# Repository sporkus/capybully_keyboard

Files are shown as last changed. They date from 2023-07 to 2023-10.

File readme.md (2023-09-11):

Capybully
---

Open source capactive sensing pcb for [Bully keyboard](https://mkh.works/#bully).

### Status
PCB has been tested and is fully functional with Niz and Deskeys parts.

### Specs
- MCU: stm32F072CB

### Supported layouts
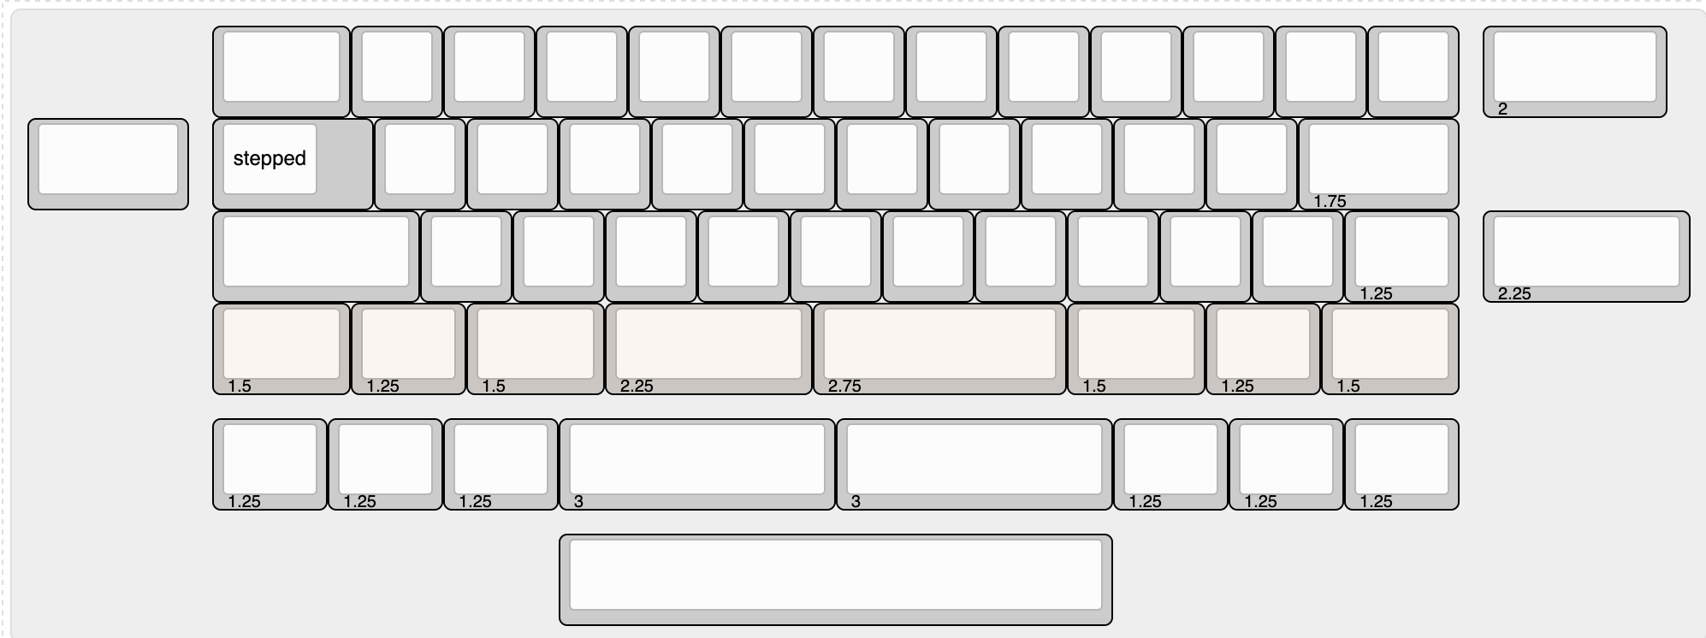
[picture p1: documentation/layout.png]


### Production files
JLCPCB [production files](pcb_production) are provided. Component positions have been verified, but as always, do your own diligence when ordering.

#### Firmware
- [See here](./firmware) for instructions, links to qmk/vial config and binaries.

#### Hardware
- 25x m2 brass standoff. 5mm long x 3mm diameter
- 50x m2 low profile screws

## Misc
#### 3D assembly preview
* [online viewer](https://3dviewer.net/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)
* [step assembly](./documentation/capybully-3D.step)

#### PCB Renders
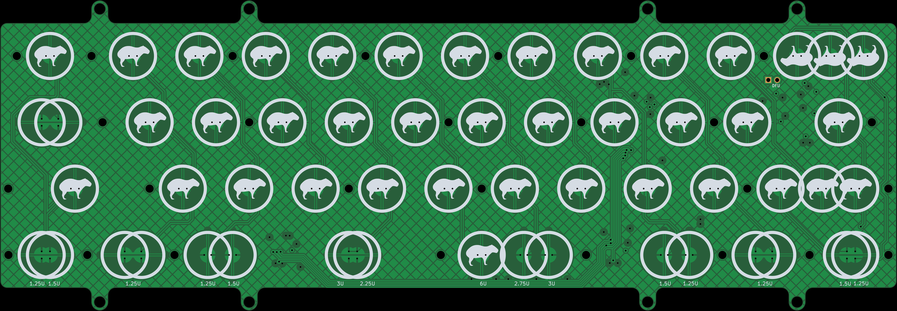
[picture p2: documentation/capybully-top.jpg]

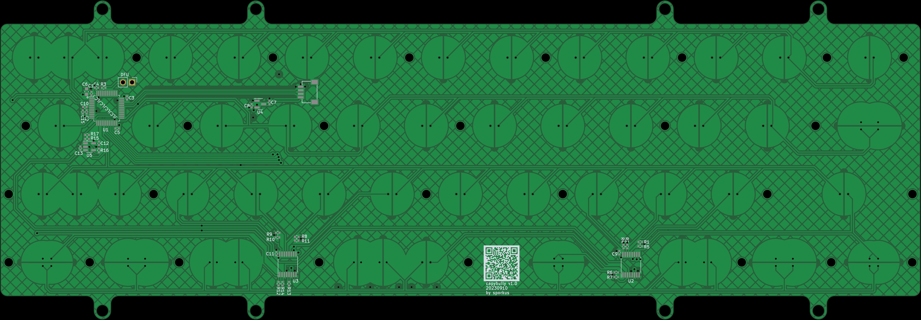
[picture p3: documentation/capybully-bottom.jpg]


#### Interactive BoM
Download and open this [html](./documentation/capybully-ibom.html) locally

#### Schematic
[pdf](./documentation/capybully-schematic.pdf)

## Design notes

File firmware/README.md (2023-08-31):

# Firmware

- [QMK and vial config](https://github.com/sporkus/qmk_userspace/tree/main/keyboards/sporkus/capybully)
- [Pre-compiled vial binary](./sporkus_capybully_vial.bin)

## First flash
Use tweezers to short the DFU pads while powering up the PCB will put it into DFU bootloader mode. Afterwards, you can use bootmagic or keycodes to enter the bootloader mode.

To flash, you can use `qmk flash` or `dfu-util` on cli. Alternatively, you can flash the binary using qmk toolbox.

## EC Matrix features
#### Tuning
The baseline for each key is different. Even if you use the same parts, they can change between assemblies. The very first time firmware is flashed, a quick auto tuning will be done (about half a minute). As long as you don't intentionally feather the keys, it should be immediately usable and not affect the tuning result.

To re-tune after assembly, you can either use the keycode `EC_CLR` to reset the configuration. 

#### Actuation point adjustment
Use the keycodes `EC_AP_I`/`EC_AP_D` to increase/decrease the actuation point.

#### Advanced users
More options can be enabled in the config.h file.
- `ECSM_TUNE_ON_BOOT`: re-tune on every boot. It's not really necessary and increases write cycles to the flash memory.
- `ECSM_DEBUG`: prints EC config and readings in console.

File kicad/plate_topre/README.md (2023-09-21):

# Topre plate

Layout option is:
* 2.25/2.75 split bars (uses 2u housing)
* Stepped/non-stepped caps lock

Other layout options are removed because it's unlikely to work well in a single plate.

See [keyboard layout editor](./capybully_plate.json) json file for reference.

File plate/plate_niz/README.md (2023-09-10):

# Niz plate

Main layout option is 2.25/2.75 split bars. 2u+ keys uses costar stabilizers.

See [keyboard layout editor](./capybully_plate.json) json file for reference.

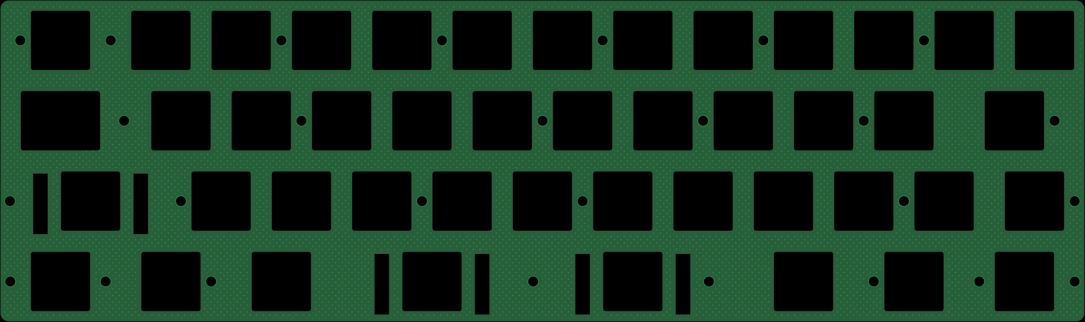
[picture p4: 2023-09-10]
plate/plate_niz/plate-top.jpg

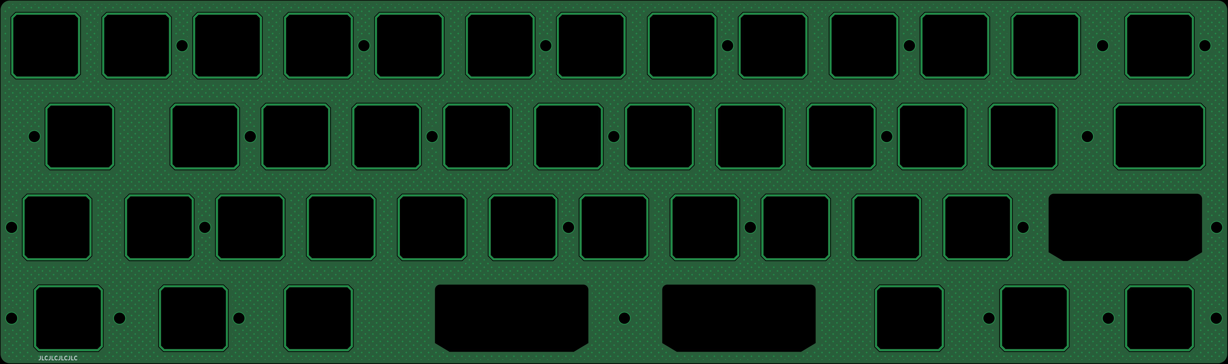
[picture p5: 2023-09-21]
plate/topre/plate-bottom.jpg

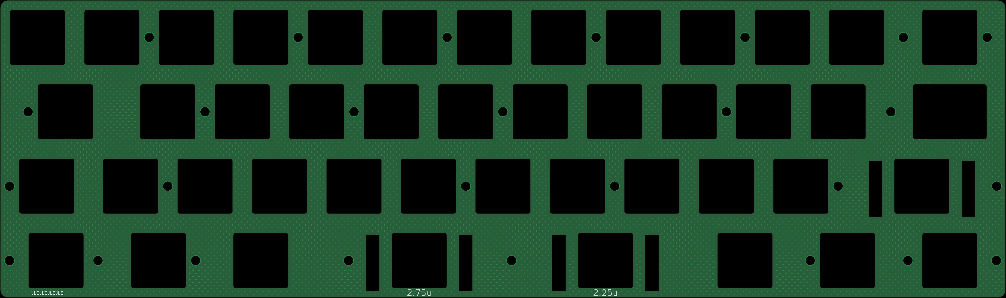
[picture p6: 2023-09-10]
plate/plate_niz/plate-bottom.jpg

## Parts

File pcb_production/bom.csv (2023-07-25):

Designator | Footprint | Quantity | Value | LCSC Part #
C1, C10, C2, C3, C4 | 0402 | 5 | 100nF | C307331
C11, C12, C5, C9 | 0402 | 4 | 100n | C307331
C13 | 0402 | 1 | 220pF NP0 | C1530
C15 | 0402 | 1 | 1u
C6 | 0603 | 1 | 10uF
C7, C8 | 0402 | 2 | 1uF | C52923
H1, H10, H11, H12, H13, H14, H15, H16, H17, H18, H19, H2, H20, H21, H22, H23, H24, H25, H26, H27, H3, H4, H5, H6, H7, H8, H9 | MountingHole_2.2mm_M2_DIN965 | 27 | MountingHole
J1 | JST-SR-4 | 1 | SM04B-SRSS-TB(LF)(SN)
R1, R10, R11, R12, R13, R14, R15, R2, R4, R5, R6, R7, R8, R9 | 0402 | 14 | 100k | C25741
R16 | 0402 | 1 | 1k | C11702
R3 | 0402 | 1 | 10k
U1 | LQFP-48_7x7mm_P0.5mm | 1 | STM32F072CBT6
U2, U3 | TSSOP-16_4.4x5mm_P0.65mm | 2 | 74HC4051 | C5645
U4 | SOT-23 | 1 | XC6206PxxxMR-Regulator_Linear | C5446
U5 | SOT-23-5 | 1 | OPA354

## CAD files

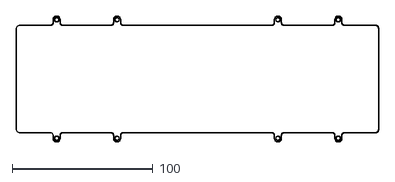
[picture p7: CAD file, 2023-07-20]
documentation/capybully-Edge_Cuts.dxf
257.2 x 89.2

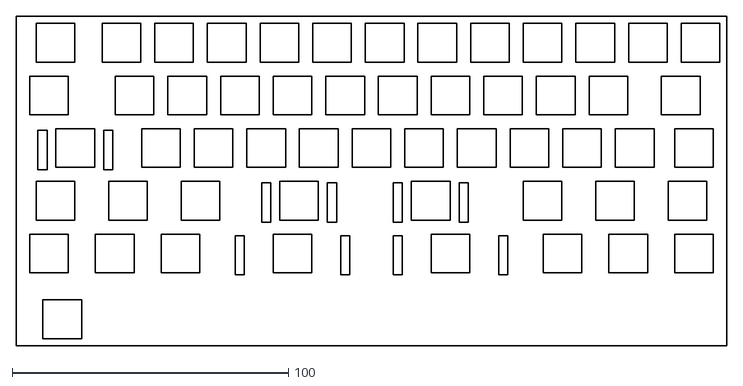
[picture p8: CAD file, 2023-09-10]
kicad/plate_niz/kle_reference.dxf
257.2 x 119.1

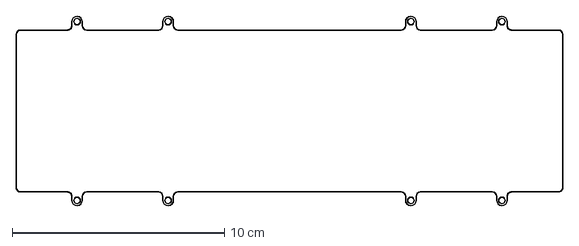
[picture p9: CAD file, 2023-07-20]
misc/edgecuts.dxf
25.7 x 8.92 cm

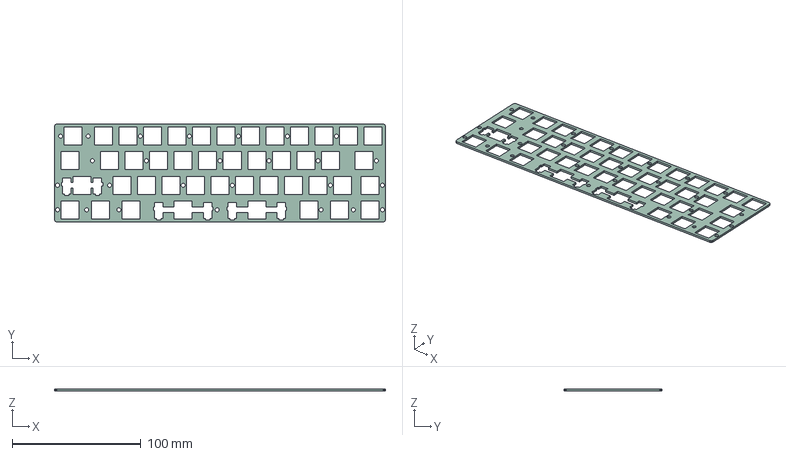
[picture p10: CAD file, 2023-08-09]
plate/plate-3D.step
257.2 x 76.2 x 1.58 mm

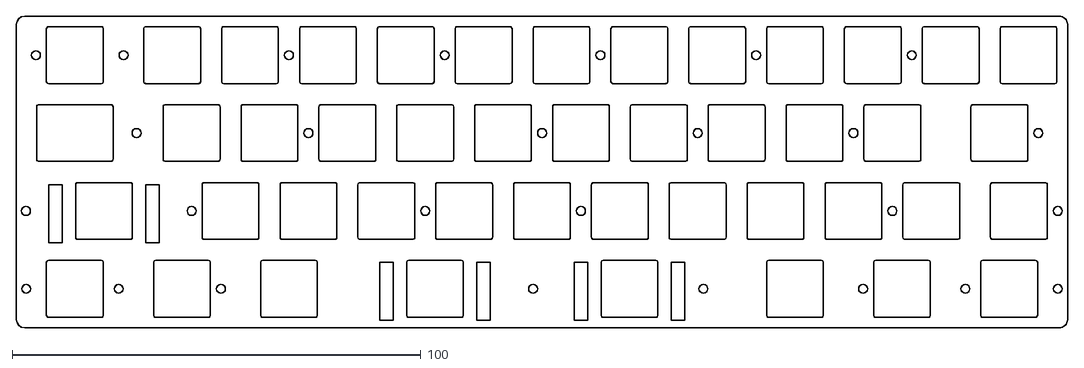
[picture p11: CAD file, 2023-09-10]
plate/plate_niz/plate-Edge_Cuts.dxf
257.2 x 76.2

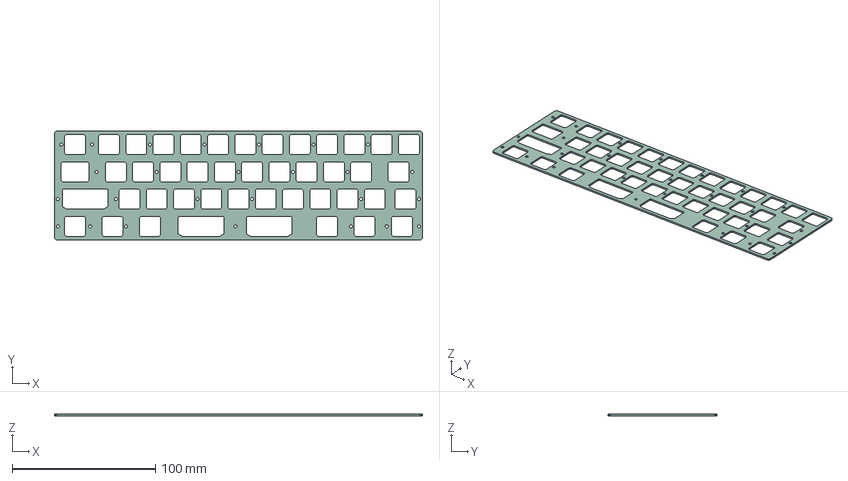
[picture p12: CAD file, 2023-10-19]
plate/topre/plate-3D.step
257.2 x 76.2 x 1.18 mm

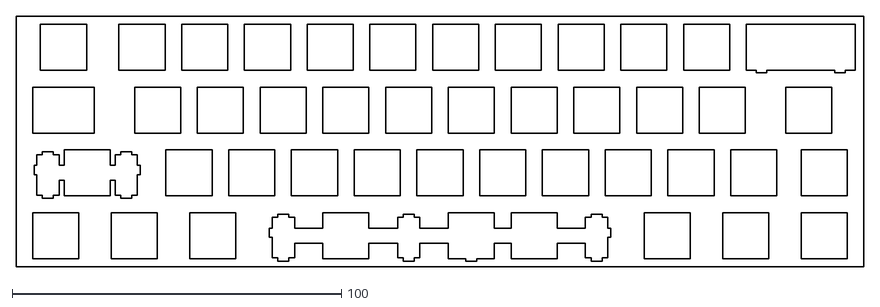
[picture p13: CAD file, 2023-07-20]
misc/3u_6u_plate.dxf
257.2 x 76.2

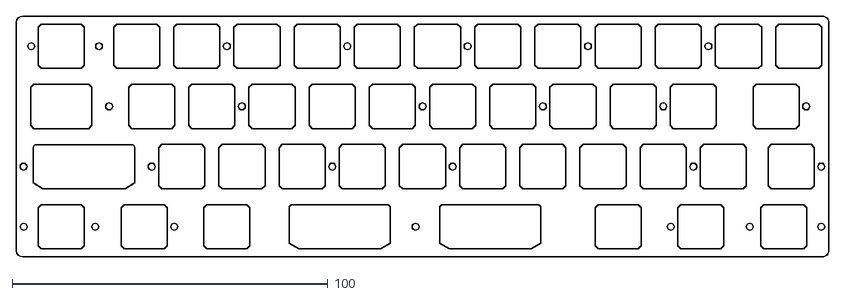
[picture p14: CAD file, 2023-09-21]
plate/topre/plate-Edge_Cuts.dxf
257.2 x 76.2

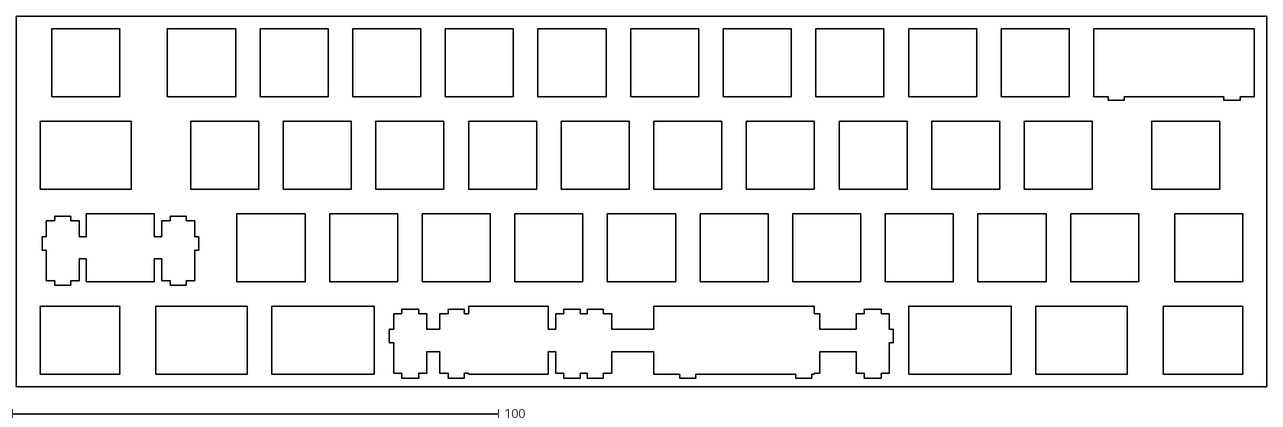
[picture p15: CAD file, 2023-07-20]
misc/b75c8ba988832cb8d0211764c9687bd89171a611_switch.dxf
257.2 x 76.2

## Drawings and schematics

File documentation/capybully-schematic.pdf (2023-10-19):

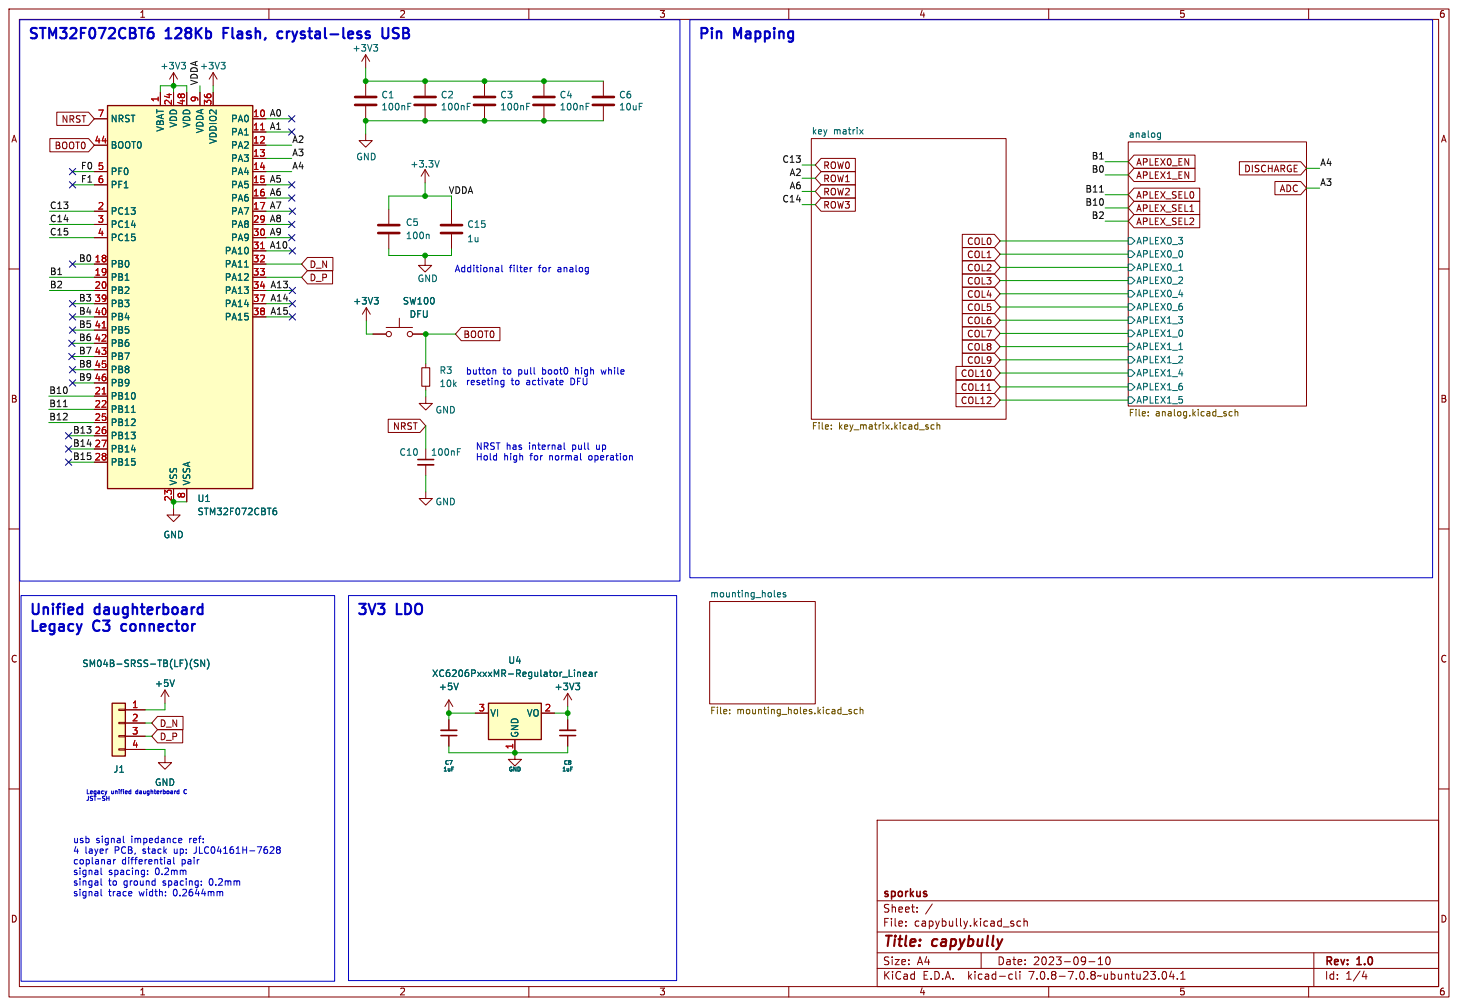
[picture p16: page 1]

1 PA0 10 PA1 11 PA2 12 PA3 13 PA4 14 PA5 15 PA6 16 PA7 17 PB0 18 PB1 19 PC13 2 PB2 20 PB10 21 PB11 22 VSS 23 VDD 24 PB12 25 PB13 26 PB14 27 PB15 28 PA8 29 PC14 3 PA9 30 PA10 31 PA11 32 PA12 33 PA13 34 VDDIO2 36 PA14 37 PA15 38 PB3 39 PC15 4 PB4 40 PB5 41 PB6 42 PB7 43 BOOT0 44 PB8 45 PB9 46 VDD 48 PF0 5 PF1 6 NRST 7 VSSA

button to pull boot0 high while

J1 SM04B-SRSS-TB(LF)(SN) 1

File: capybully.kicad_sch Sheet: / sporkus

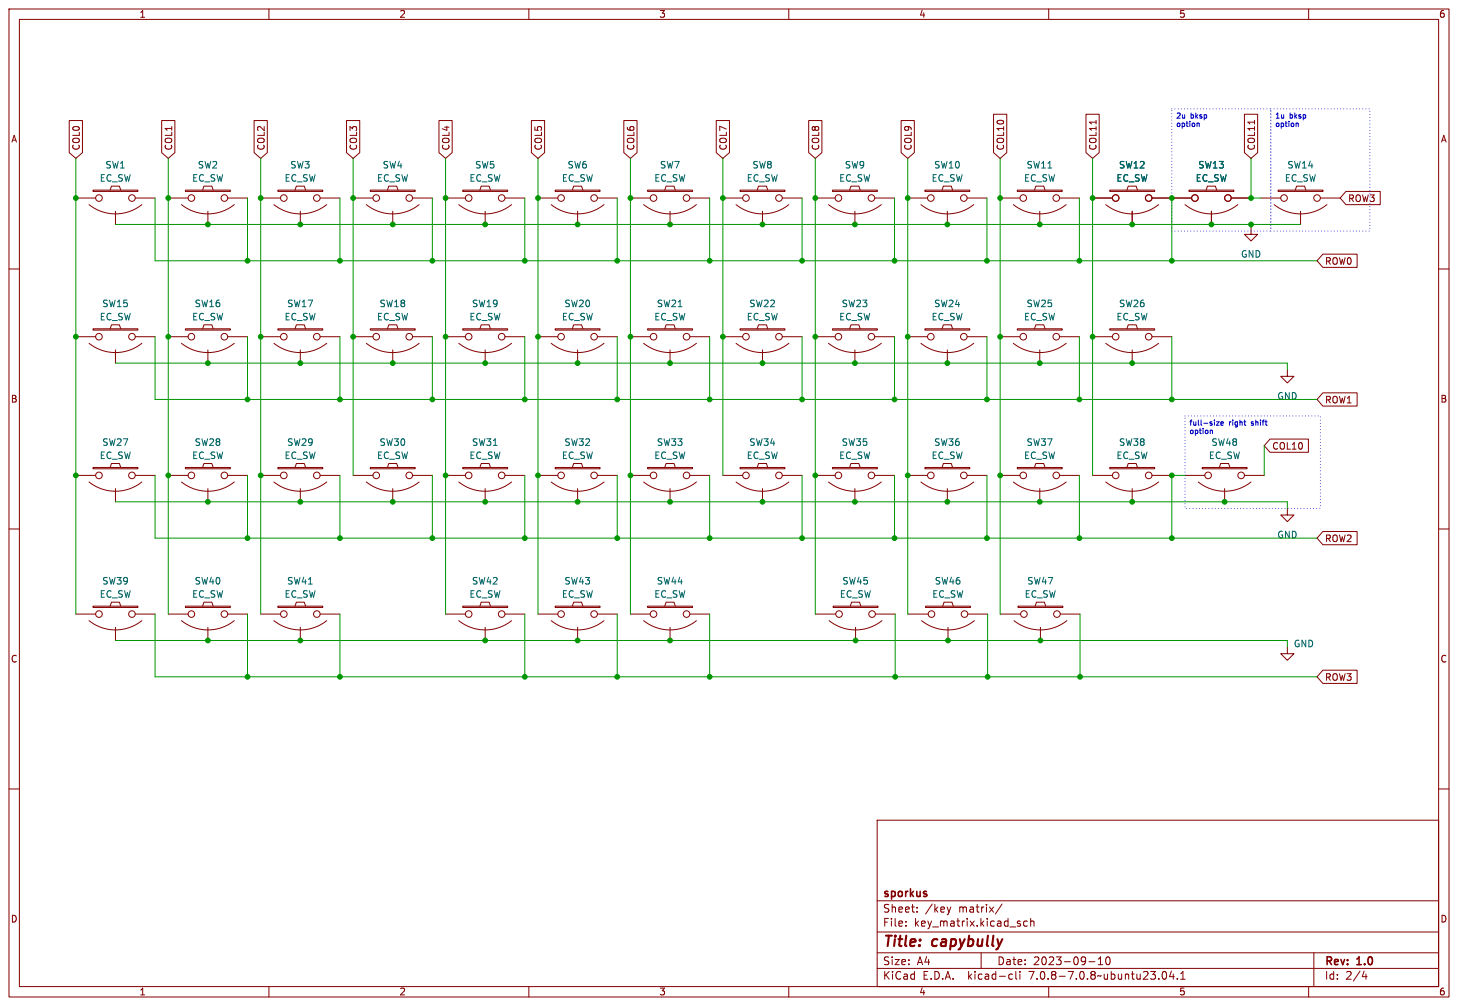
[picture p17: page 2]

File: key_matrix.kicad_sch Sheet: /key matrix/ sporkus SW43 EC_SW

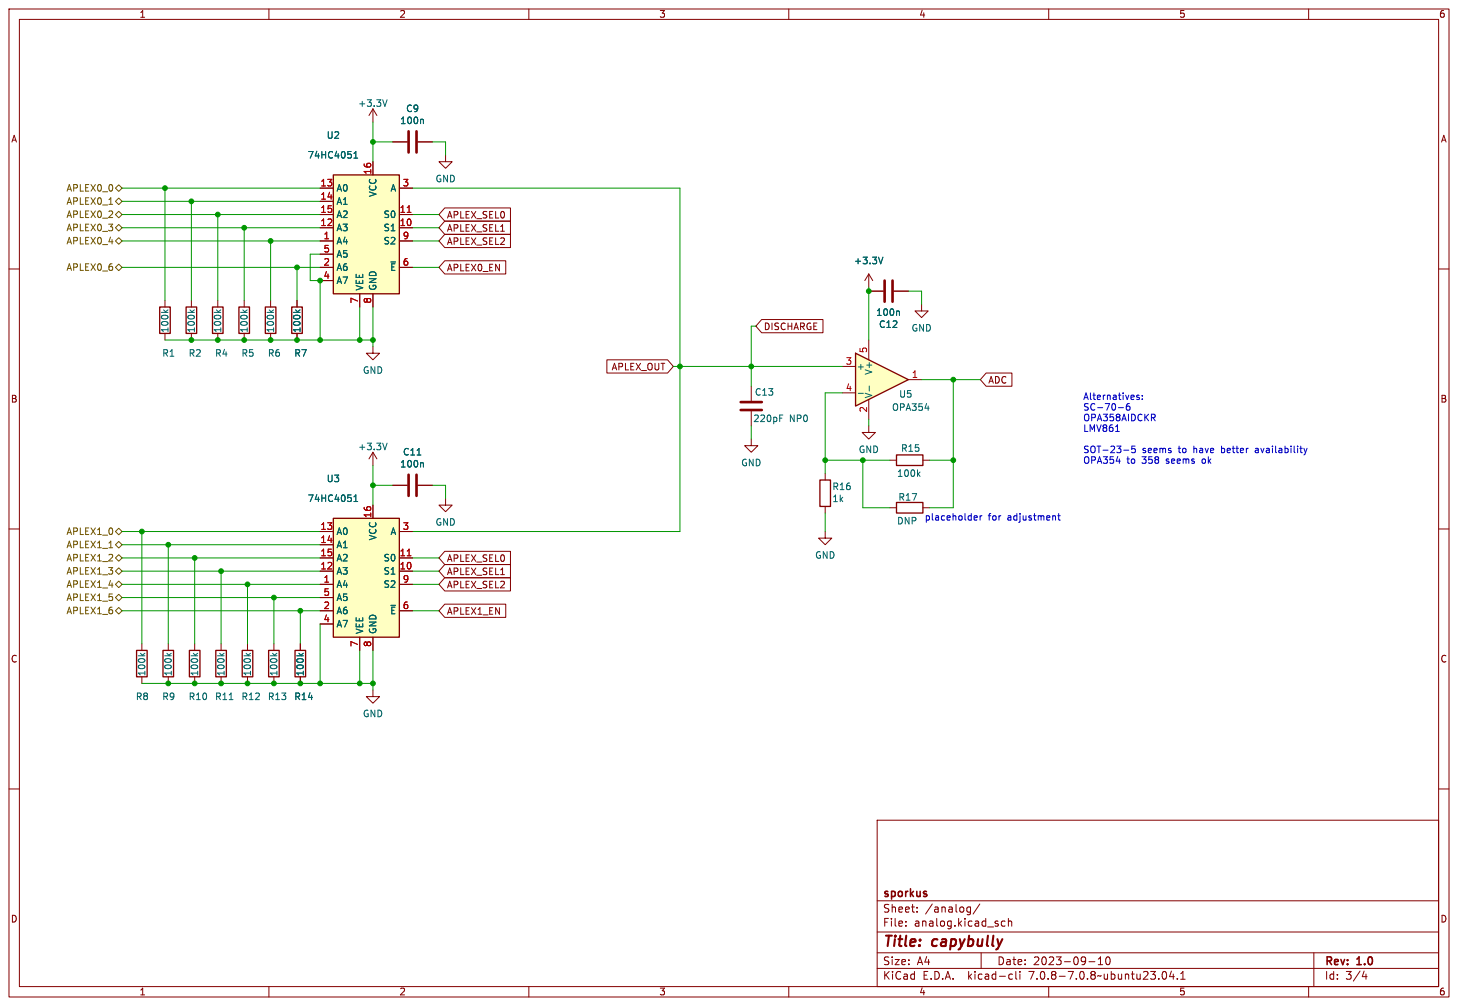
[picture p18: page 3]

sporkus
File: analog.kicad_sch Sheet: /analog/
Id: 3/4 Title: capybully

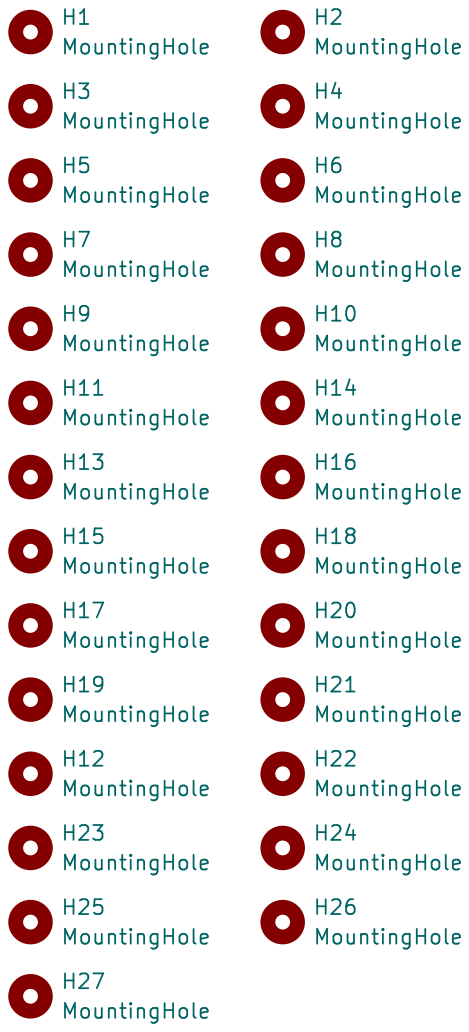
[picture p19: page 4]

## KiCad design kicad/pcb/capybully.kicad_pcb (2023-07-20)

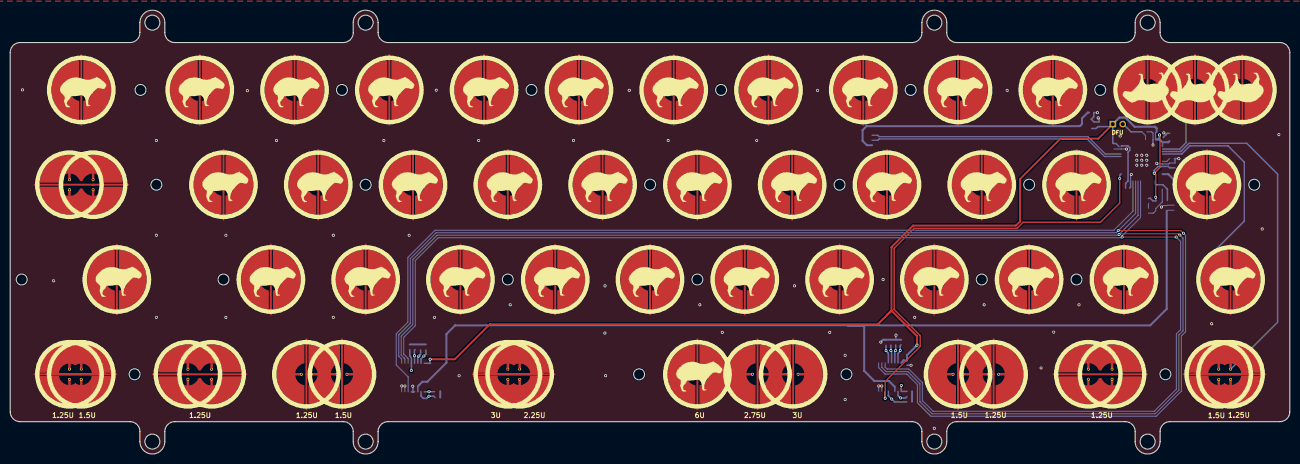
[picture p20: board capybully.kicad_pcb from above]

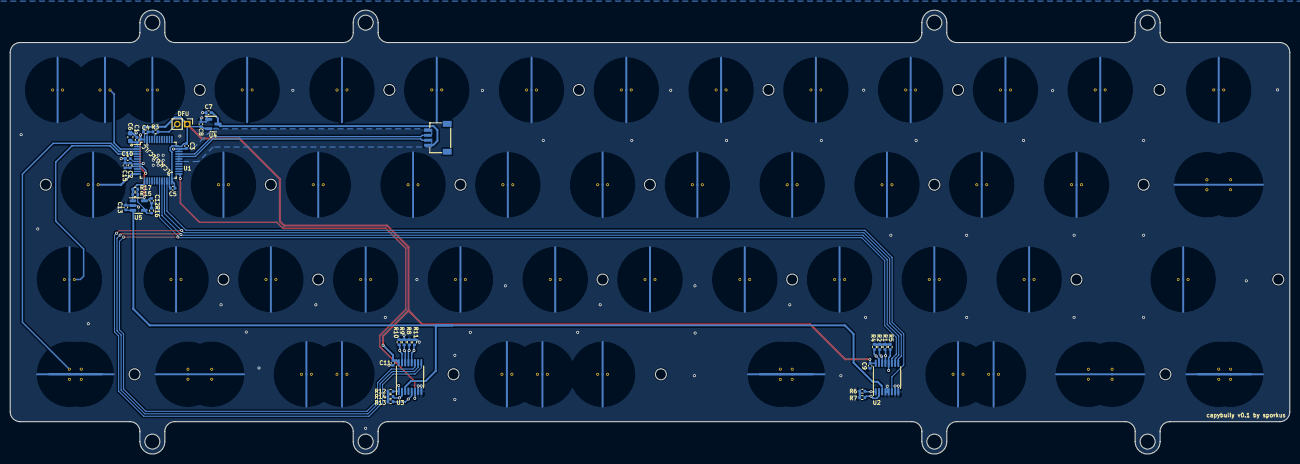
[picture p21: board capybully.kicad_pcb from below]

Board: 4 copper layers, 257.2 x 89.2 mm, 107 parts (38 on the bottom side), 32 nets.

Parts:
C1, C2, C3, C4, C10: 100nF; C_0402_1005Metric
C5, C9, C11, C12: 100n; C_0402_1005Metric
C6: 10uF; C_0603_1608Metric
C7, C8: 1uF; C_0402_1005Metric
C13: 220pF NP0; C_0402_1005Metric
C15: 1u; C_0402_1005Metric
H1, H2, H3, H4, H5, H6, H7, H8, H9, H10, H11, H12, H13, H14, H15, H16, H17, H18, H19, H20, H21, H22: MountingHole; MountingHole_2.2mm_M2_DIN965
J1: SM04B-SRSS-TB(LF)(SN); JST-SR-4
R1, R2, R4, R5, R6, R7, R8, R9, R10, R11, R12, R13, R14, R15: 100k; R_0402_1005Metric
R3: 10k; R_0402_1005Metric
R16: 1k; R_0402_1005Metric
R17: DNP; R_0402_1005Metric
SW1, SW2, SW3, SW4, SW5, SW6, SW7, SW8, SW9, SW10, SW11, SW12, SW13, SW14, SW16, SW17, SW18, SW19, SW20, SW21, SW22, SW23, SW24, SW25, SW26, SW27, SW28, SW29, SW30, SW31, SW32, SW33, SW34, SW35, SW36, SW37, SW38, SW43: EC_SW; capy_pad_1U
SW15: EC_SW; ecs_pad_1.75u_1.25u_combo
SW39, SW42, SW47: EC_SW; ecs_pad_combo_0.125u_offset
SW40, SW46: EC_SW; ecs_pad_combo_0.25u_offset
SW41, SW44, SW45: EC_SW; ecs_pad_combo_0.375u_offset
SW100: DFU; PinHeader_1x02_P2.00mm_Vertical
U1: STM32F072CBT6; LQFP-48_7x7mm_P0.5mm
U2, U3: 74HC4051; TSSOP-16_4.4x5mm_P0.65mm
U4: XC6206PxxxMR-Regulator_Linear; SOT-23
U5: OPA354; SOT-23-5

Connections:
+3V3: C1.1, C2.1, C3.1, C4.1, C5.1, C6.1, C8.2, C9.2, C11.2, C12.2, C15.1, SW100.1, U1.1 (VBAT), U1.9 (VDDA), U1.24 (VDD), U1.36 (VDDIO2), U1.48 (VDD), U2.16 (VCC), U3.16 (VCC), U4.2 (VO), U5.5 (V+)
+5V: C7.2, J1.1, U4.3 (VI)
ADC: R15.1, R17.1, U1.13 (PA3), U5.1
APLEX_0_A0: R1.1, SW2.2, SW16.2, SW28.2, SW40.1, U2.13 (A0)
APLEX_0_A1: R2.1, SW3.2, SW17.2, SW29.2, SW41.2, U2.14 (A1)
APLEX_0_A2: R4.1, SW4.2, SW18.2, SW30.2, U2.15 (A2)
APLEX_0_A3: R5.1, SW1.2, SW15.1, SW27.1, SW39.2, U2.12 (A3)
APLEX_0_A4: R6.1, SW5.2, SW19.2, SW31.2, SW42.1, U2.1 (A4)
APLEX_0_A6: R7.1, SW6.2, SW20.2, SW32.2, SW43.1, U2.2 (A6)
APLEX_0_EN: U1.22 (PB11), U2.6 (~E)
APLEX_1_A0: R8.1, SW8.2, SW22.2, SW34.2, U3.13 (A0)
APLEX_1_A1: R9.1, SW9.2, SW23.2, SW35.2, U3.14 (A1)
APLEX_1_A2: R10.1, SW10.2, SW24.2, SW36.2, SW45.2, U3.15 (A2)
APLEX_1_A3: R11.1, SW7.2, SW21.2, SW33.2, SW44.2, U3.12 (A3)
APLEX_1_A4: R12.1, SW11.2, SW25.2, SW37.2, SW46.2, U3.1 (A4)
APLEX_1_A5: R13.1, SW13.1, SW14.2, U3.5 (A5)
APLEX_1_A6: R14.1, SW12.2, SW26.2, SW38.2, SW47.1, U3.2 (A6)
APLEX_1_EN: U1.25 (PB12), U3.6 (~E)
APLEX_OUT: C13.1, U2.3 (A), U3.3 (A), U5.3 (+)
APLEX_SEL0: U1.19 (PB1), U2.11 (S0), U3.11 (S0)
APLEX_SEL1: U1.20 (PB2), U2.10 (S1), U3.10 (S1)
APLEX_SEL2: U1.21 (PB10), U2.9 (S2), U3.9 (S2)
BOOT0: R3.1, SW100.2, U1.44 (BOOT0)
D_N: J1.2, U1.32 (PA11)
D_P: J1.3, U1.33 (PA12)
GND: C1.2, C2.2, C3.2, C4.2, C5.2, C6.2, C7.1, C8.1, C9.1, C10.2, C11.1, C12.1, C13.2, C15.2, J1.4, R1.2, R2.2, R3.2, R4.2, R5.2, R6.2, R7.2, R8.2, R9.2, R10.2, R11.2, R12.2, R13.2, R14.2, R16.2, SW1.3 (SG), SW2.3 (SG), SW3.3 (SG), SW4.3 (SG), SW5.3 (SG), SW6.3 (SG), SW7.3 (SG), SW8.3 (SG), SW9.3 (SG), SW10.3 (SG), SW11.3 (SG), SW12.3 (SG), SW13.3 (SG), SW14.3 (SG), SW15.3 (SG), SW16.3 (SG), SW17.3 (SG), SW18.3 (SG), SW19.3 (SG), SW20.3 (SG), SW21.3 (SG), SW22.3 (SG), SW23.3 (SG), SW24.3 (SG), SW25.3 (SG), SW26.3 (SG), SW27.3 (SG), SW28.3 (SG), SW29.3 (SG), SW30.3 (SG), SW31.3 (SG), SW32.3 (SG), SW33.3 (SG), SW34.3 (SG), SW35.3 (SG), SW36.3 (SG), SW37.3 (SG), SW38.3 (SG), SW39.3 (SG), SW40.3 (SG), SW41.3 (SG), SW42.3 (SG), SW43.3 (SG), SW44.3 (SG), SW45.3 (SG), SW46.3 (SG), SW47.3 (SG), U1.8 (VSSA), U1.23 (VSS), U1.35 (VSS), U1.47 (VSS), U2.4 (A7), U2.5 (A5), U2.7 (VEE), U2.8 (GND), U3.4 (A7), U3.7 (VEE), U3.8 (GND), U4.1 (GND), U5.2 (V-)
NRST: C10.1, U1.7 (NRST)
unnamed: R15.2, R16.1, R17.2, U5.4 (-)
ROW0: SW1.1, SW2.1, SW3.1, SW4.1, SW5.1, SW6.1, SW7.1, SW8.1, SW9.1, SW10.1, SW11.1, SW12.1, SW13.2, SW14.1, U1.2 (PC13)
ROW1: SW15.2, SW16.1, SW17.1, SW18.1, SW19.1, SW20.1, SW21.1, SW22.1, SW23.1, SW24.1, SW25.1, SW26.1, U1.12 (PA2)
ROW2: SW27.2, SW28.1, SW29.1, SW30.1, SW31.1, SW32.1, SW33.1, SW34.1, SW35.1, SW36.1, SW37.1, SW38.1, U1.4 (PC15)
ROW3: SW39.1, SW40.2, SW41.1, SW42.2, SW43.2, SW44.1, SW45.1, SW46.1, SW47.2, U1.3 (PC14)

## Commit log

2023-07-25 should be ok for proto order
    [3u_plate.dxf, analog.kicad_sch, bom.csv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]
2023-08-09 adding right shift option
    [2u_bars.dxf, bom.csv, capybully.kicad_sch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]
2023-08-17 updated plate files
    [0228ccc4e69e6ee422fff3eb3f1efb149f1d0e64_switch.dxf, 3u_plate.dxf, bom.csv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]
2023-08-17 change plate thickness to 1.2mm
2023-08-17 plate files workflow
    [0228ccc4e69e6ee422fff3eb3f1efb149f1d0e64_switch.dxf, bom.csv, designators.csv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]
2023-08-17 adding edgecut to mounting hole
2023-08-18 fixed plate silkscreen
    [0228ccc4e69e6ee422fff3eb3f1efb149f1d0e64_switch.dxf, plate.step, plate.stl]
2023-08-18 fix 3u sch for kibot
    [plate.kicad_sch]
2023-08-23 trying universal plate
    [0fed8a3cc3e58210befdf5ebeac6e90852bd800c_switch.dxf]
2023-08-23 change topre plate to non-stepped cap
    [bom.csv, designators.csv, mounting_holes.kicad_sch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]
2023-09-10 updated footprint and fixing plate tolerance
    [0228ccc4e69e6ee422fff3eb3f1efb149f1d0e64_switch.dxf, 0fed8a3cc3e58210befdf5ebeac6e90852bd800c_switch.dxf, 3u_plate.dxf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]
2023-09-10 add qr
    [analog.kicad_sch, capybully.kicad_sch, key_matrix.kicad_sch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]
2023-09-11 update 3d model
    [key_matrix.kicad_sch]
2023-09-21 removing layout options for plates
    [plate.kicad_sch]
2023-10-19 v1 release
    [bom.csv, designators.csv, positions.csv]
